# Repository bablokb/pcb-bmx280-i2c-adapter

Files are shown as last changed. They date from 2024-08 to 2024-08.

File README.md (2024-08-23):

An Adapter PCB for BME280/BMP280 Breakouts Supporting Stemma/Qt and Grove
=========================================================================

Here are the KiCAD (v7) design-files for a small adapter PCB adding
Stemma/Qt and/or Grove I2C-connectors to a BME280/BMP280 breakout. These
breakouts are omnipresent under names like GY-BME280/GY-BMP280. Be
careful, both breakouts look identical and some sellers cheat you: they
send the cheaper BMP280-variant instead of the BME280-variant.

The breakout suports two Stemma/Qt on top and bottom. On the top
side, you can also add two horizontal Grove-connectors. For the
bottom side, only vertical Grove-connectors will work.

The directory `3D` contains design-files for an enclosure in OpenSCAD format.
You also need the [BOSL2-Library](https://github.com/BelfrySCAD/BOSL2).

Schematic
---------

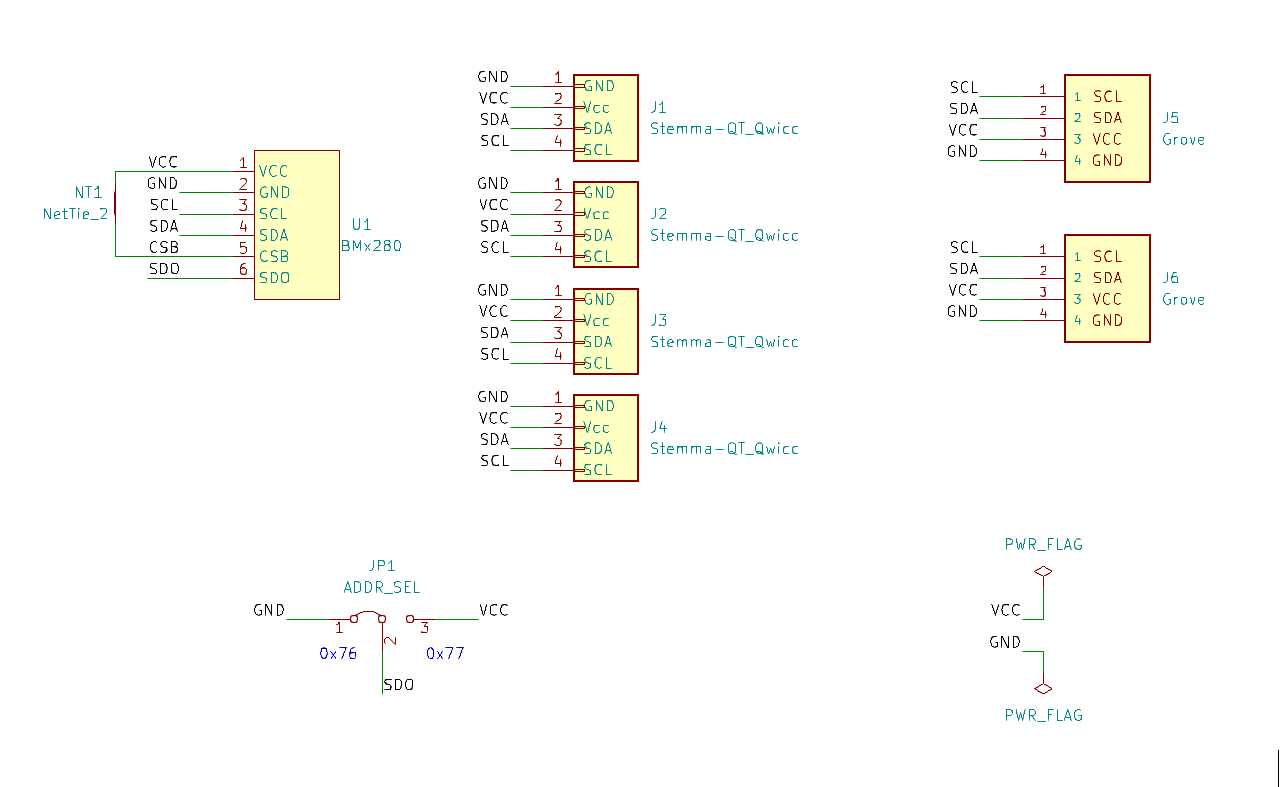
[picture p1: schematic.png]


Layout
------

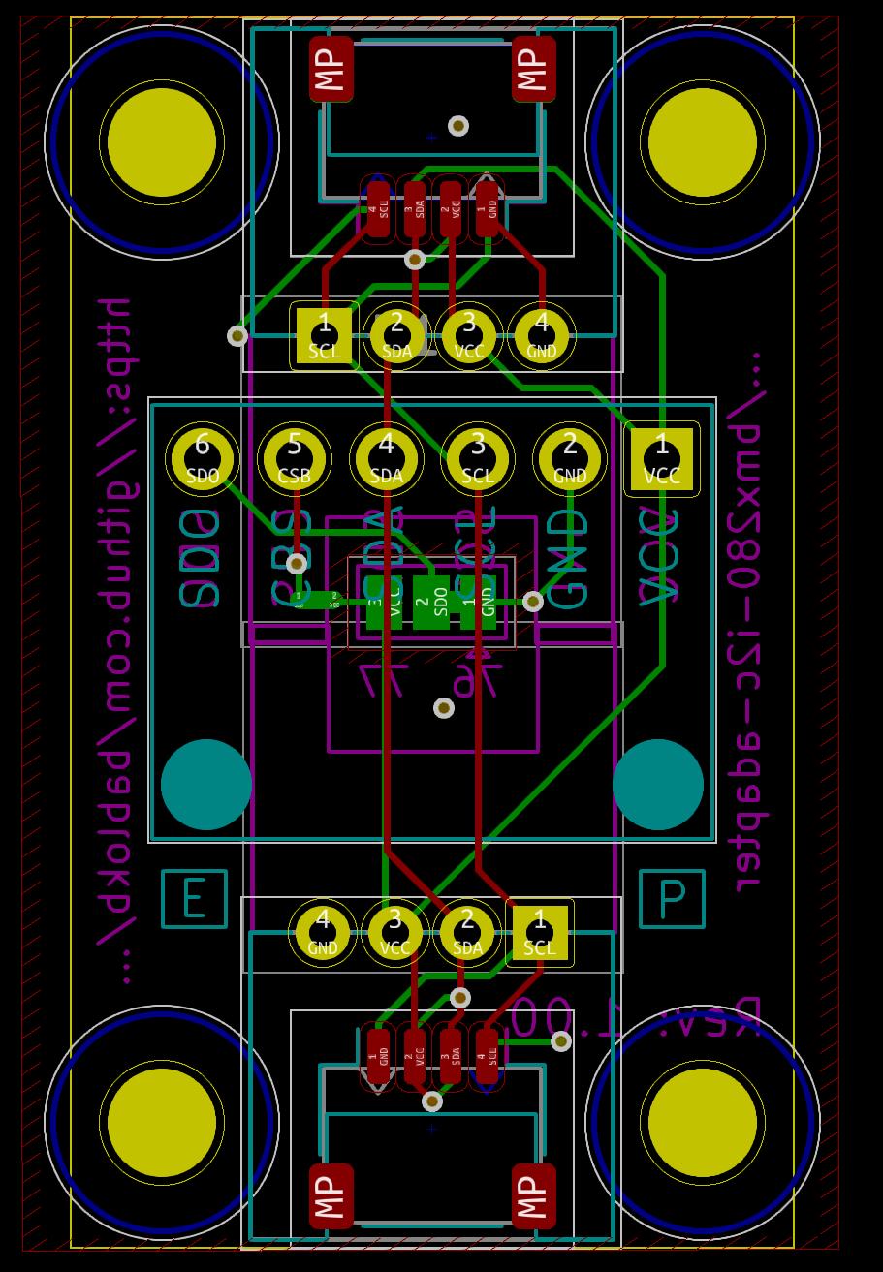
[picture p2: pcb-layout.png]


3D-Views
--------


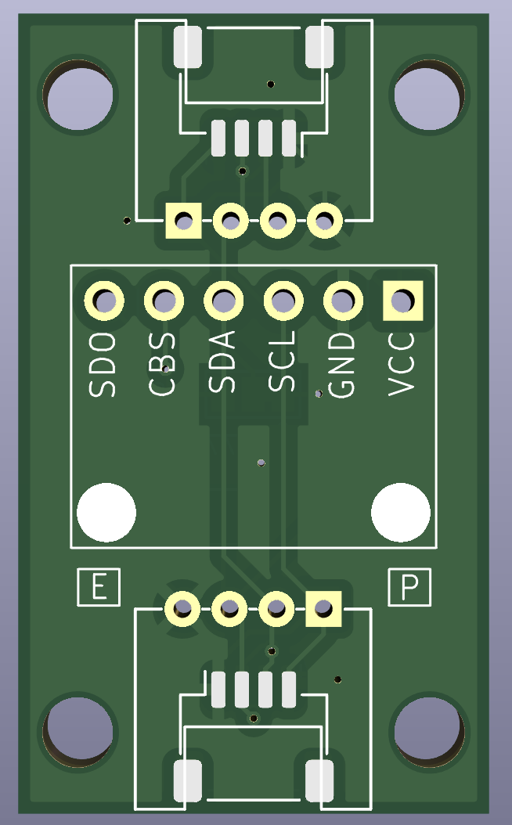
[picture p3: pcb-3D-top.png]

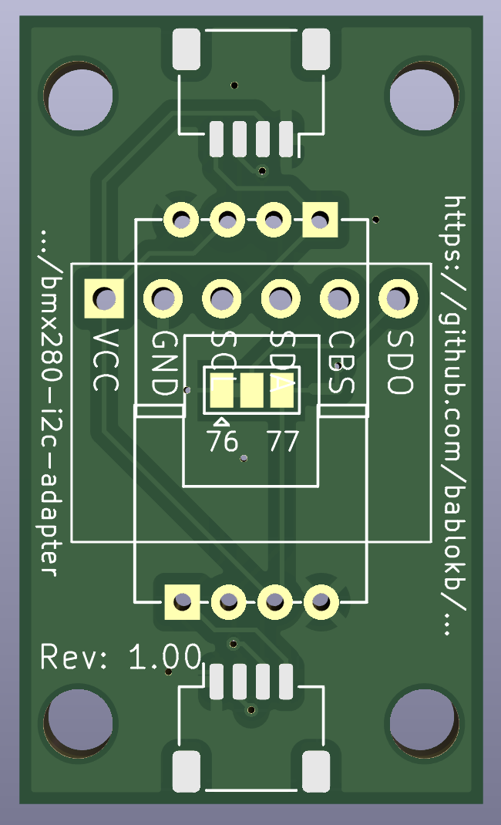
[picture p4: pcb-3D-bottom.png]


License
-------

[![CC BY-SA 4.0][cc-by-sa-shield]][cc-by-sa]

This work is licensed under a
[Creative Commons Attribution-ShareAlike 4.0 International
License][cc-by-sa].

[][cc-by-sa]

[cc-by-sa]: http://creativecommons.org/licenses/by-sa/4.0/
[cc-by-sa-image]: https://licensebuttons.net/l/by-sa/4.0/88x31.png
[cc-by-sa-shield]:
https://img.shields.io/badge/License-CC%20BY--SA%204.0-lightgrey.svg

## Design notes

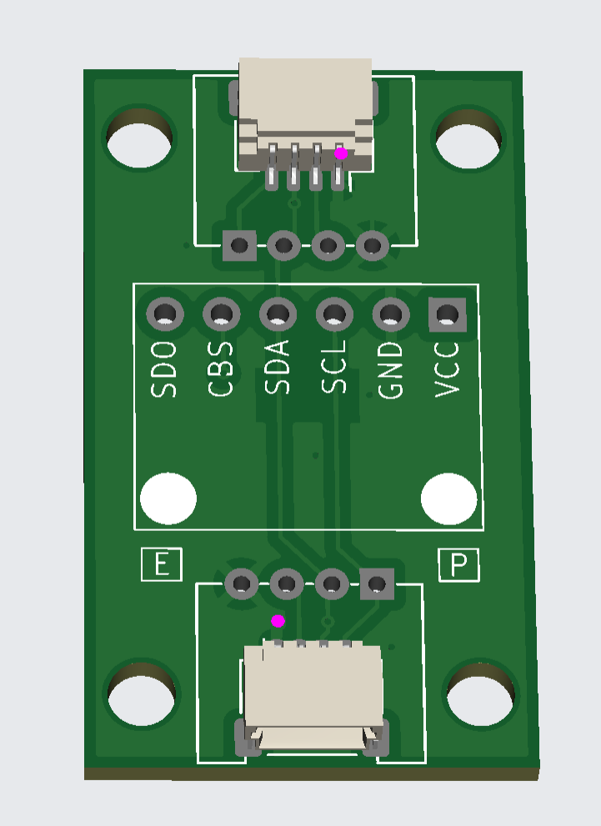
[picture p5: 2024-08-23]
pcb-3D-top-jlcpcb.png

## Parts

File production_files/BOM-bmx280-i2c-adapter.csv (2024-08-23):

Comment | Designator | Footprint | LCSC
Stemma-QT_Qwicc | J2,J4 | JST_SH_SM04B-SRSS-TB_1x04-1MP_P1.00mm_Horizontal | C160404

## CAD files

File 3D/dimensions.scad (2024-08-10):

// -----------------------------------------------------------------------------
// 3D-Model (OpenSCAD): generic dimensions.
//
// Author: Bernhard Bablok
// License: GPL3
//
// https://github.com/bablokb/pcb-bmx280-i2c-adapter
// ---------------------------------------------------------------------------

$fa = 1;
$fs = 0.4;
$fn= $preview ? 32 : 128;

fuzz = 0.01;
w2 = 0.86;                 // 2 walls
w4 = 1.67;                 // 4 walls
gap = 0.2;                 // gap pcb to case

b = 1.4;               // base thickness

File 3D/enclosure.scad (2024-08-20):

// -----------------------------------------------------------------------------
// 3D-Model (OpenSCAD): enclosure for sensor+i2c-adapter.
//
// Author: Bernhard Bablok
// License: GPL3
//
// https://github.com/bablokb/pcb-bmx280-i2c-adapter
// ---------------------------------------------------------------------------

include <dimensions.scad>
include <BOSL2/std.scad>

// dimensions   ----------------------------------------------------------------

x_pcb   = 20.0;
y_pcb   = 34.0;
z_pcb   = 1.6;
xo_screw = 2.525;
yo_screw = 3.45;
r_screw  = 1.50; 

x_support = 5.60;           // support (for solder joints at the back)
y_support = x_support;
z_support = b + 2.00;

z1_bot  = z_support + z_pcb;        // wall with 4 perimeters from bottom
z2_bot  = z1_bot + 4.5;             // wall with 2 perimeters from bottom
z2_top  = b + 4.5;                  // wall with 2 perimeters from top

yb_sensor = 11.20;                             // distance sensor to bottom
yt_sensor = 10.50;                             // distance sensor to top
y_sensor  = y_pcb - yb_sensor - yt_sensor;

x_stemma = 8.0;
y_stemma = 5.5;
z_stemma = 3.2;

x_grove = 10;
z_grove = 0;      // TBD

x_case = x_pcb + 2*gap + 2*w4;
y_case = y_pcb + 2*gap + 2*w4;

d_screw = 4.5;    // enclosure screw

// --- supports   --------------------------------------------------------------

module supports() {
  x = x_support + w4 + gap;
  y = y_support + w4 + gap;
  x_off = x_case/2-x/2;
  y_off = y_case/2-y/2;
  move([-x_off,-y_off,0]) cuboid([x,y,z_support],anchor=BOTTOM+CENTER);
  move([-x_off,+y_off,0]) cuboid([x,y,z_support],anchor=BOTTOM+CENTER);
  move([+x_off,-y_off,0]) cuboid([x,y,z_support],anchor=BOTTOM+CENTER);
  move([+x_off,+y_off,0]) cuboid([x,y,z_support],anchor=BOTTOM+CENTER);
}

// --- screws   ----------------------------------------------------------------

module screws() {
  x_off = x_pcb/2-xo_screw;
  y_off = y_pcb/2-yo_screw;
  r     = r_screw - 2*gap;
  move([-x_off,-y_off,z_support-fuzz]) cyl(r=r,h=z_pcb,anchor=BOTTOM+CENTER);
  move([-x_off,+y_off,z_support-fuzz]) cyl(r=r,h=z_pcb,anchor=BOTTOM+CENTER);
  move([+x_off,-y_off,z_support-fuzz]) cyl(r=r,h=z_pcb,anchor=BOTTOM+CENTER);
  move([+x_off,+y_off,z_support-fuzz]) cyl(r=r,h=z_pcb,anchor=BOTTOM+CENTER);
}

// --- bottom part   -----------------------------------------------------------

module bottom() {
  difference() {
    union() {
      // base plate
      cuboid([x_case,y_case,b],anchor=BOTTOM+CENTER);
      // suport and screws
      supports();
      screws();
      // walls around sensor
      rect_tube(size=[x_case,y_case],wall=w4,h=z1_bot,anchor=BOTTOM+CENTER);
      rect_tube(size=[x_case,y_case],wall=w2,h=z2_bot,anchor=BOTTOM+CENTER);
    }
    // cutouts Stemma
    move([0,-y_case/2+w4/2,z1_bot])
                 cuboid([x_stemma,2*w4,z2_bot-b+fuzz],anchor=BOTTOM+CENTER);
    move([0,+y_case/2-w4/2,z1_bot])
                 cuboid([x_stemma,2*w4,z2_bot-b+fuzz],anchor=BOTTOM+CENTER);
    // cutout screw
    move([0,y_pcb/2-y_support/2,-fuzz]) cyl(d=d_screw,h=b+2*fuzz,anchor=BOTTOM+CENTER);
  }
}

// --- top part   --------------------------------------------------------------

module top() {
  difference() {
    union() {
      // base plate
      cuboid([x_case,y_case,b],anchor=BOTTOM+CENTER);
      // walls around sensor
      rect_tube(size=[x_case-2*w2,y_case-2*w2],
                wall=w4,h=z2_top,anchor=BOTTOM+CENTER);
      // walls around Stemma
      move([0,-y_case/2+y_stemma/2+w4+w2-fuzz,0])
        rect_tube(size=[x_stemma+2*w2,y_stemma+2*w2],
                  wall=w2,h=z2_top,anchor=BOTTOM+CENTER);
      move([0,+y_case/2-y_stemma/2-w4-w2+fuzz,0])
        rect_tube(size=[x_stemma+2*w2,y_stemma+2*w2],
                  wall=w2,h=z2_top,anchor=BOTTOM+CENTER);
    }
    // cutouts Stemma
    move([0,-y_case/2+1.5*w2+y_stemma/2-fuzz,-fuzz])
          cuboid([x_stemma,3*w2+y_stemma,z2_top+z_pcb-b+2*fuzz],anchor=BOTTOM+CENTER);
    move([0,+y_case/2-1.5*w2-y_stemma/2+fuzz,-fuzz])
          cuboid([x_stemma,3*w2+y_stemma,z2_top+z_pcb-b+2*fuzz],anchor=BOTTOM+CENTER);
    // cutouts ventilation
    move([0,0,-fuzz]) cuboid([x_pcb/2,w4,b+2*fuzz],anchor=BOTTOM+CENTER);
    move([0,3*w4,-fuzz]) cuboid([x_pcb/2,w4,b+2*fuzz],anchor=BOTTOM+CENTER);
    move([0,-3*w4,-fuzz]) cuboid([x_pcb/2,w4,b+2*fuzz],anchor=BOTTOM+CENTER);
  }
}

// --- top-level object   ----------------------------------------------------

//bottom();
top();

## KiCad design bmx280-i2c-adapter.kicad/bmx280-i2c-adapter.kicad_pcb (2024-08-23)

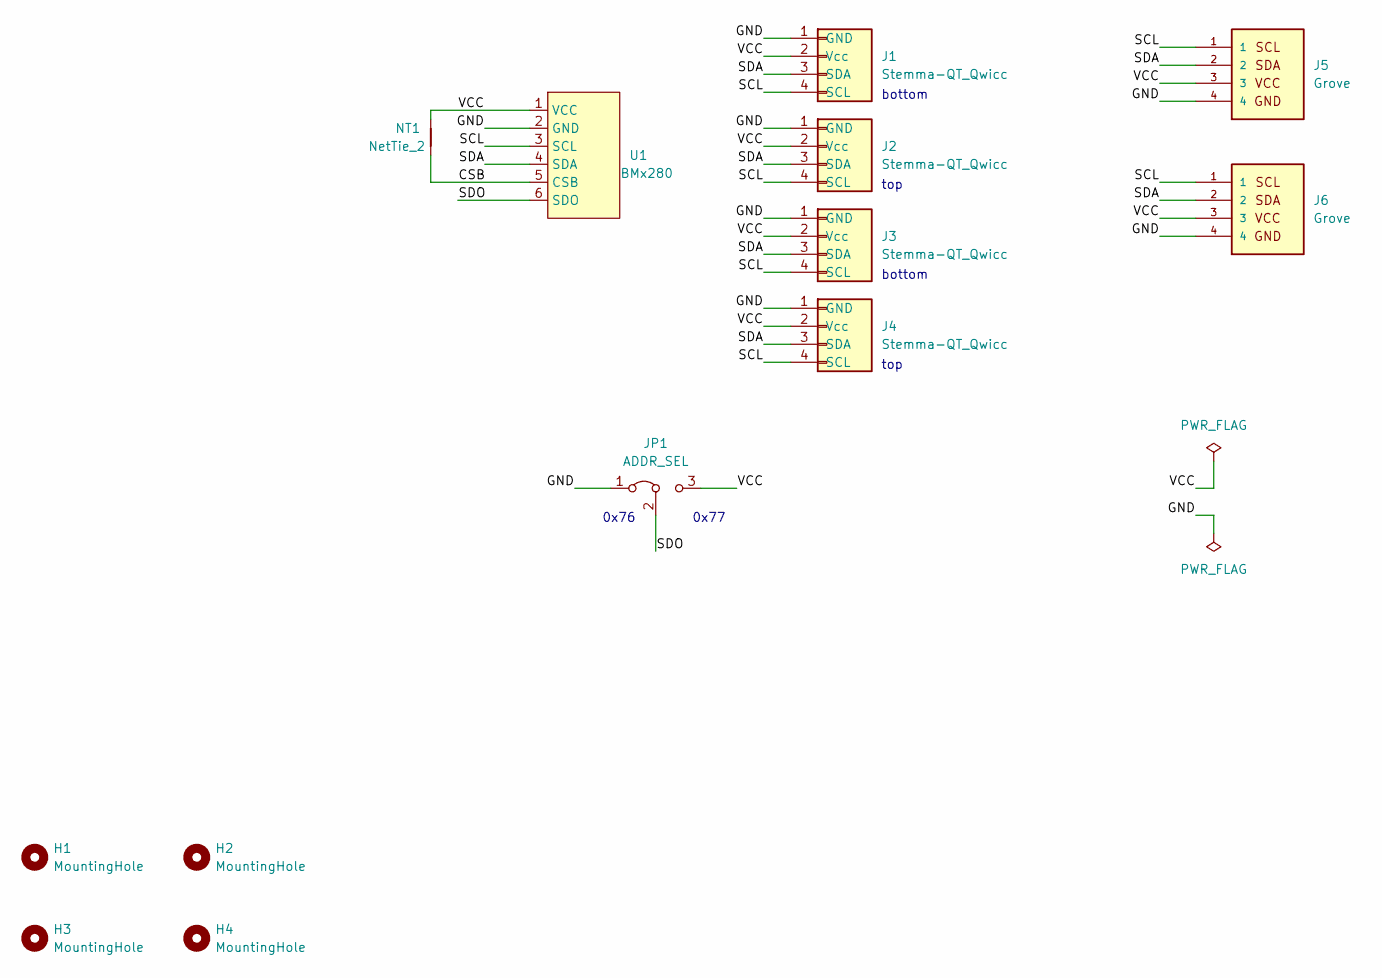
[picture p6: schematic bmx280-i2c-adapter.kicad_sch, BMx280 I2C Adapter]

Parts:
H1, H2, H3, H4: MountingHole; MountingHole_3mm
J1, J2, J3, J4: Stemma-QT_Qwicc; JST_SH_SM04B-SRSS-TB_1x04-1MP_P1.00mm_Horizontal; LCSC C160404
J5, J6: Grove; grove_horizontal
JP1: ADDR_SEL; SolderJumper-3_P1.3mm_Bridged12_Pad1.0x1.5mm
NT1: NetTie_2; NetTie-2_SMD_Pad0.5mm
U1: BMx280; BMx280_Breakout

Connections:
/CSB: NT1.1, U1.5 (CSB)
/GND: J1.1 (GND), J2.1 (GND), J3.1 (GND), J4.1 (GND), J5.4, J6.4, JP1.1 (A), U1.2 (GND)
/SCL: J1.4 (SCL), J2.4 (SCL), J3.4 (SCL), J4.4 (SCL), J5.1, J6.1, U1.3 (SCL)
/SDA: J1.3 (SDA), J2.3 (SDA), J3.3 (SDA), J4.3 (SDA), J5.2, J6.2, U1.4 (SDA)
/SDO: JP1.2 (C), U1.6 (SDO)
/VCC: J1.2 (Vcc), J2.2 (Vcc), J3.2 (Vcc), J4.2 (Vcc), J5.3, J6.3, JP1.3 (B), NT1.2, U1.1 (VCC)

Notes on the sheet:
0x77
top
bottom
0x76

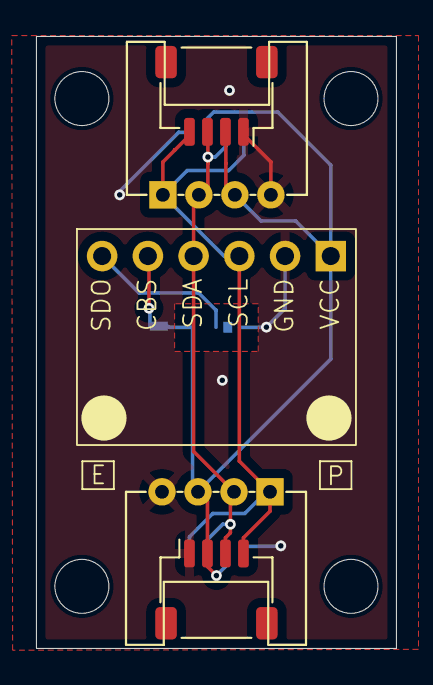
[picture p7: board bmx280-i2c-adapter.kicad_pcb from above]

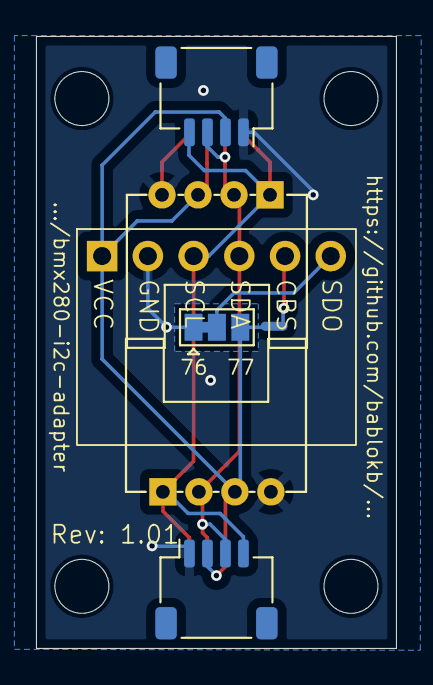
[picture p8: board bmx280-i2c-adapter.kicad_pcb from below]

Board: 2 copper layers, 20.0 x 34.0 mm, 13 parts (4 on the bottom side), 6 nets.

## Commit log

2024-08-10 first iteration of enclosure
    [dimensions.scad, enclosure.scad]
2024-08-10 second iteration: add screw-hole and walls around Stemma; fix top-height
    [enclosure.scad]
2024-08-20 add some depth to Stemma/Qt cutout
    [enclosure.scad]
2024-08-23 added note about enclosure
2024-08-23 Rev 1.01: add assembly for Stemma/Qt on top side
    [BOM-bmx280-i2c-adapter.csv, bmx280-i2c-adapter.kicad_pcb, bmx280-i2c-adapter.kicad_sch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]
